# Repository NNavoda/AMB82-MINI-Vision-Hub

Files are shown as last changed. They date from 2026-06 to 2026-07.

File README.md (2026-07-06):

# AMB82-MINI Vision Hub & Distributed Robotic Car Platform

> **Platform:** Realtek AMB82-MINI, ESP32, ESP32-C3  
> **Status:** `v1.4 — ESP-NOW Mecanum Car + AI Vision Hub + Head Tracker`

---

## 📌 Project Overview

This repository contains the firmware for a **distributed, multi-node autonomous robotic car system**. The system is decoupled into multiple independent nodes communicating over Wi-Fi and ESP-NOW:
1. **Vision Hub (AMB82-MINI)**: A dedicated AI camera unit streaming live video over RTSP and running real-time object detection (YOLOv4-Tiny) using its on-chip NPU.
2. **Motor Control Node (ESP32)**: Receives low-latency ESP-NOW commands to independently drive 4 DC motors (via two TB6612FNG drivers) in an omnidirectional Mecanum drive configuration, and controls the camera Pan/Tilt servos.
3. **Gesture Glove Controller (ESP32-C3)**: A wearable glove equipped with an MPU-6050 IMU that calculates Mecanum kinematics from hand tilt/twist and transmits them directly to the car via ESP-NOW.
4. **Head Tracker Unit (ESP32-C3)**: A head-mounted IMU (MPU-9250) that calculates head Pitch and Yaw to seamlessly aim the Pan/Tilt Vision Hub camera in real time via ESP-NOW.

### System Architecture

```text
┌────────────────────────────────────────────────────────────────────────┐
│                   Distributed Robotic Car Platform                     │
│                                                                        │
│  ┌───────────────┐           ┌──────────────────────────────┐          │
│  │ Gesture Glove │  ESP-NOW  │        ESP32 Car Node        │          │
│  │ (ESP32-C3 +   ├──────────►│  (ESP32 + 2x TB6612FNG +     │          │
│  │  MPU-6050)    │ Protocol  │   Mecanum Wheels + Servos)   │          │
│  └───────────────┘           └────────────┬─────────────────┘          │
│                                           │                            │
│  ┌───────────────┐  ESP-NOW               │                            │
│  │ Head Tracker  ├──────────►             │                            │
│  │ (ESP32-C3 +   │                        │                            │
│  │  MPU-9250)    │           ┌────────────▼─────────────────┐          │
│  └───────────────┘           │  Viewer / Driver Dashboard   │          │
│                              │  (VLC Player / Phone VR)     │          │
│  ┌───────────────┐   WiFi    │                              │          │
│  │  AMB82-MINI   ├──────────►│                              │          │
│  │  Vision Hub   │ RTSP / AP │                              │          │
│  └───────────────┘           └──────────────────────────────┘          │
└────────────────────────────────────────────────────────────────────────┘
```

---

## ✨ Features

### 📡 **Vision Hub (AMB82-MINI)**
- **RTSP Stream**: H.264 · VGA (640×480) · 20fps · 1 Mbps · Low-latency GOP=10
- **Object Detection**: YOLOv4-Tiny · INT8 NPU · COCO 80 classes
- **Live OSD Overlay**: Bounding boxes + class labels composited before H.264 encoding

### 🚗 **Car Control Node (ESP32)**
- **ESP-NOW Receiver**: Ultra-low latency, direct peer-to-peer connection.
- **Mecanum Omnidirectional Drive**: Controls 4 independent motors via dual TB6612FNG H-bridges allowing for strafing, diagonal movement, and zero-radius turns.
- **Pan/Tilt Camera Gimbal**: Instantly receives angles from the head tracker and drives two servos with 16-bit PWM to smoothly aim the AMB82-MINI camera.
- **Safety Timeout**: Automatically halts all motors and centers servos if the ESP-NOW connection drops for >500ms.

### 🧤 **Gesture Glove (ESP32-C3)**
- **MPU-6050 IMU**: Fuses accelerometer and gyroscope data using a complementary filter for stable pitch/roll/yaw calculation.
- **Mecanum Kinematics**:
  - **Pitch** (Tilt Forward/Back) = Forward / Reverse Drive
  - **Roll** (Tilt Left/Right) = Strafe Left / Right
  - **Yaw** (Twist Hand) = Tank Spin in place

### 🥽 **Head Tracker Unit (ESP32-C3)**
- **MPU-9250 IMU**: Calculates true pitch/roll and integrates gyroscope Z-axis for responsive yaw mapping.
- **Zero-Drift Centering**: Remotely zeros the pan (yaw) heading simply by pressing the BOOT button on the Car Receiver.
- **Proportional Scaling**: Head movements are smoothly multiplied by a tuned sensitivity curve (Pitch x1.8, Yaw x1.5) to capture full camera range (40°–180°) effortlessly.

---

## 📁 Project Structure

```text
AMB82-MINI-Vision-Hub/
├── RTSP/
│   ├── RTSP.ino                  # AMB82-MINI Vision Hub firmware
│   └── ObjectClassList.h         # COCO 80-class lookup table
├── ESP32-Car/
│   ├── ESPNOW_Receiver/          
│   │   └── ESPNOW_Receiver.ino   # ESP32 ESP-NOW Mecanum Motor Controller
│   ├── HeadTracker_Receiver/     
│   │   └── HeadTracker_Receiver.ino # ESP32 ESP-NOW Servo Receiver (Latest)
│   ├── ESPNOW_ServoTracker/
│   │   └── ESPNOW_ServoTracker.ino # (Legacy) ESP-NOW Pan/Tilt Head Tracker
│   └── WebMotorControl/          # (Legacy) HTTP Web Dashboard Controller
├── Gesture_Glove/
│   └── Gesture_Glove.ino         # ESP32-C3 ESP-NOW IMU Glove Controller
├── HeadTracker/
│   └── HeadTracker.ino           # ESP32-C3 + MPU9250 Head Tracker Sender
├── 3D Files/                     # 3D printable parts for the robot chassis
├── .vscode/
│   └── ...                       # Editor configurations
└── README.md
```

---

## 🛠️ Hardware Requirements

- **Vision**: Realtek AMB82-MINI development board + camera module
- **Car**: ESP32 Dev Module (30-pin), 2x TB6612FNG motor drivers, 4x Mecanum wheels w/ DC Motors, Chassis.
- **Glove**: ESP32-C3 Super Mini, MPU-6050 GY-521 IMU module, 3.7V Battery.

---

## 🚀 Setup & Usage

### 1. Car Setup (ESP32)
1. Flash `ESP32-Car/ESPNOW_Receiver/ESPNOW_Receiver.ino` to the ESP32.
2. The ESP32 will boot and wait for incoming ESP-NOW packets on its MAC address.

### 2. Vision Hub (AMB82-MINI)
1. Flash `RTSP/RTSP.ino` to the AMB82-MINI.
2. Connect to its `RobotCar-Demo` Wi-Fi AP.
3. Open `rtsp://192.168.1.1:554/` in VLC Media Player to view the live object detection stream.

### 3. Gesture Glove (ESP32-C3)
1. Ensure the Car's MAC address is correctly hardcoded in `Gesture_Glove.ino`.
2. Flash `Gesture_Glove/Gesture_Glove.ino` to the ESP32-C3.
3. Put the glove on. Tilting and twisting your hand will instantly drive the Mecanum wheels.

---

## 🗺️ Roadmap

- [x] **v1.0** — Vision Hub: RTSP streaming + YOLOv4 object detection OSD
- [x] **v1.1** — Decentralized nodes: Car web controller + IMU Gesture Glove
- [x] **v1.2** — ESP-NOW upgrade: Ultra-low latency Mecanum drive kinematics
- [x] **v1.3** — Servo Protocol: Preliminary Pan/Tilt absolute tracking
- [x] **v1.4** — Head Tracker Unit: Full 2-axis independent tracking with IMU MPU-9250
- [ ] **v2.0** — Full autonomous navigation loop (Vision Hub sending UDP drive commands)

---

## 📄 License

MIT © 2026 [NNavoda](https://github.com/NNavoda)

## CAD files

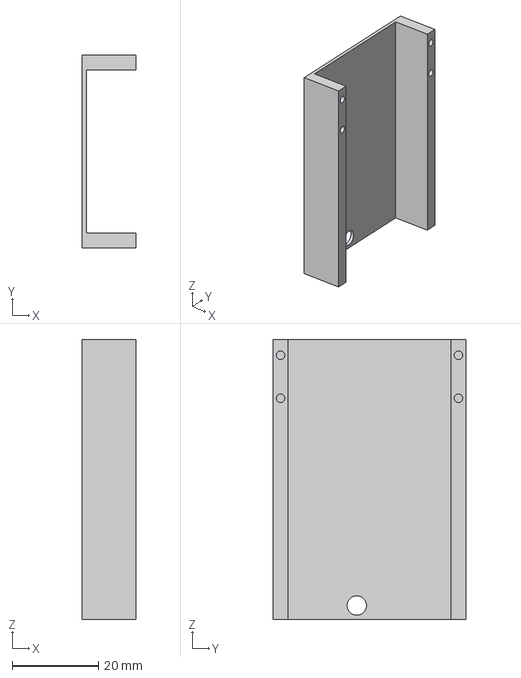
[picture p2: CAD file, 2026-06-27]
3D Files/Pan Tilt Servo/Bracket 2.3mf
12.5 x 44.9 x 65.0 mm

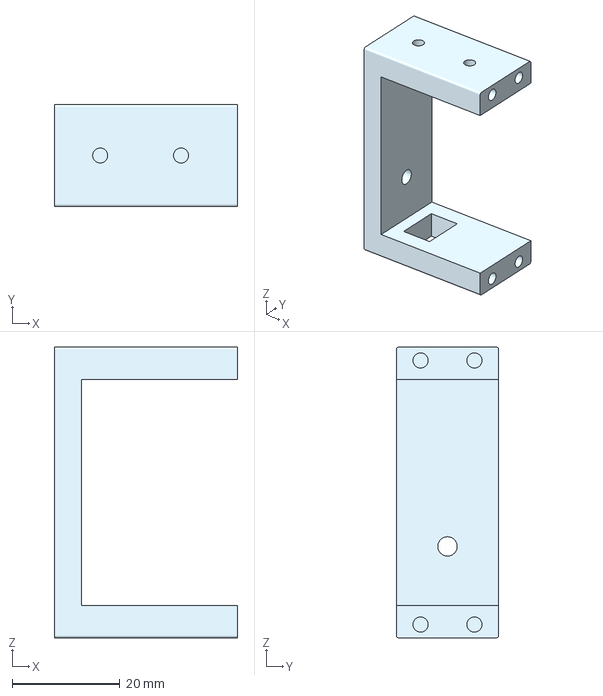
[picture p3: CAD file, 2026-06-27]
3D Files/Pan Tilt Servo/Top Bracket.3mf
34.0 x 19.0 x 54.0 mm

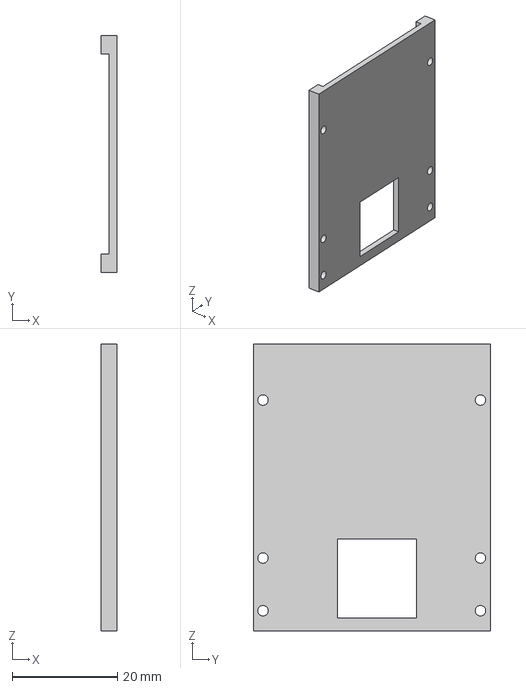
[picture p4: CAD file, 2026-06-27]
3D Files/Pan Tilt Servo/Bracket1 v2.3mf
3.00 x 45.0 x 54.5 mm

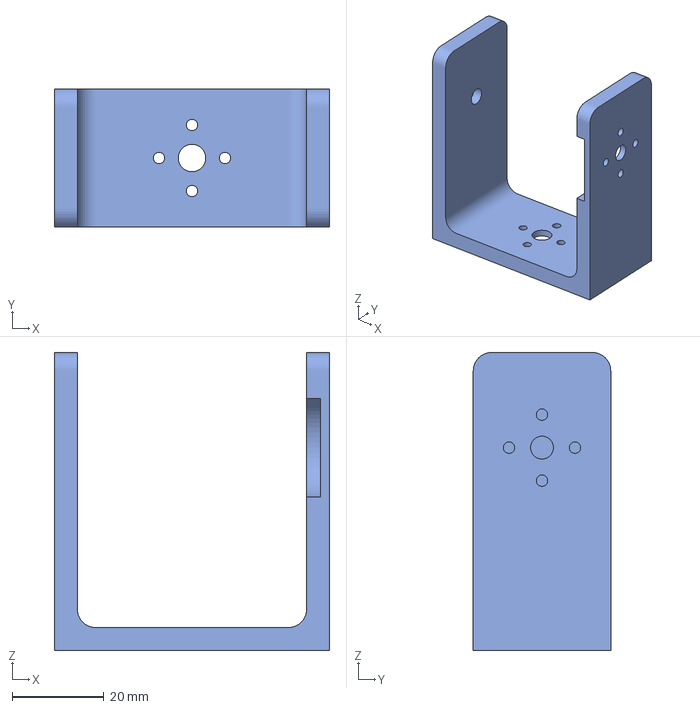
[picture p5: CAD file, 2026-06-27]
3D Files/Pan Tilt Servo/Bottom Bracket.3mf
60.0 x 30.0 x 65.0 mm

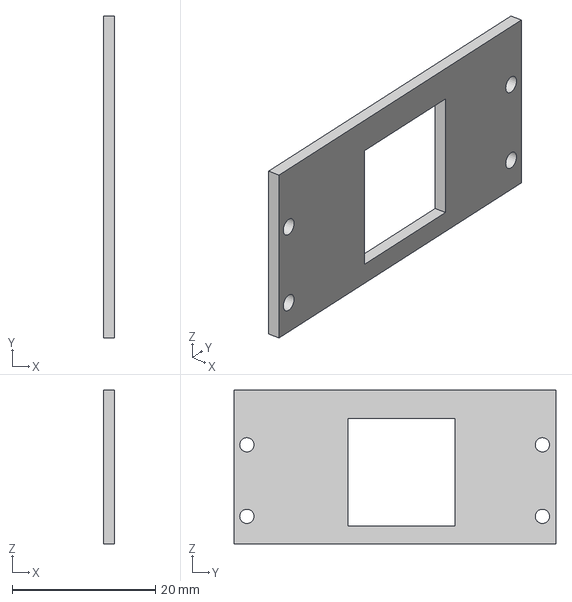
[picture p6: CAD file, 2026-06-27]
3D Files/Pan Tilt Servo/Bracket1.3mf
1.50 x 45.0 x 21.5 mm

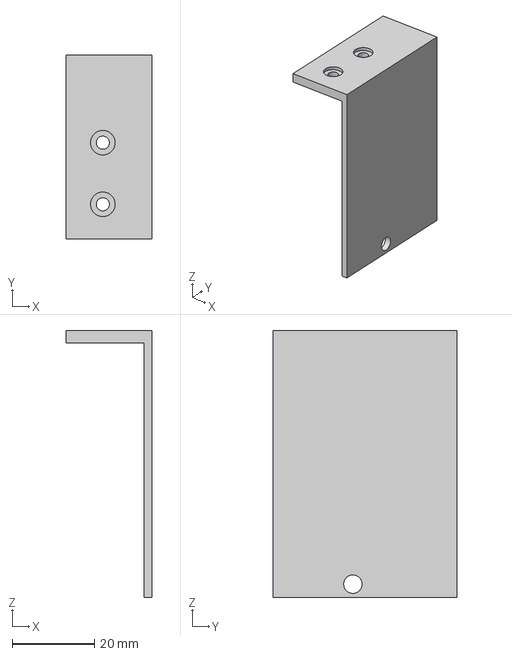
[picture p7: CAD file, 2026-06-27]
3D Files/Pan Tilt Servo/Bracket 3.3mf
21.0 x 44.9 x 65.0 mm

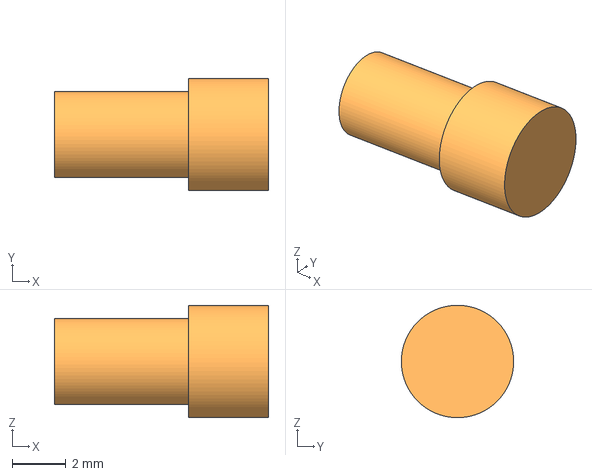
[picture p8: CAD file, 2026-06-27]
3D Files/Pan Tilt Servo/Mount.3mf
8.00 x 4.20 x 4.20 mm

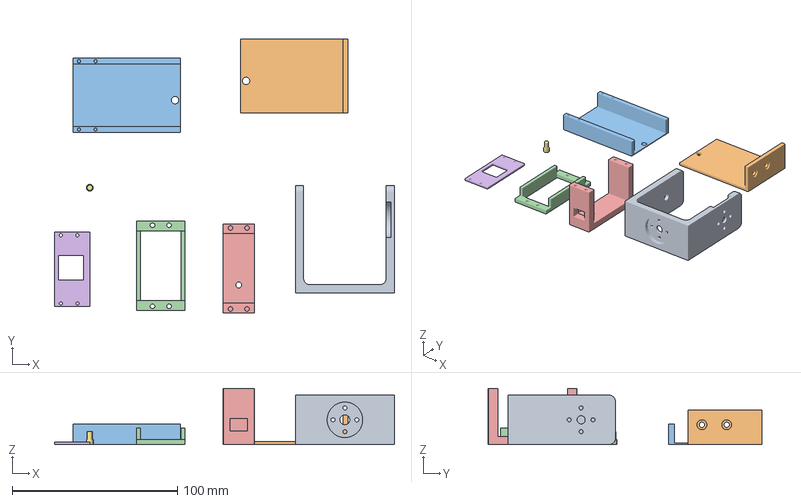
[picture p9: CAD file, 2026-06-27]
3D Files/Pan Tilt Servo/Base.3mf
205.7 x 165.9 x 34.0 mm

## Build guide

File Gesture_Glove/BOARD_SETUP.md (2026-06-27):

# ESP32-C3 Super Mini — Board Setup & Driver Fix Guide

## Problem: Board not appearing in Device Manager

The ESP32-C3 Super Mini uses a **USB-CDC on-chip** interface (no external USB-UART chip like CH340 or CP2102).
Windows requires a specific driver + a boot trick to enumerate it.

---

## Step 1 — Force the board into Download/Bootloader Mode

The board will **not** appear in Device Manager unless it is in Download Mode.

| Step | Action |
|---|---|
| 1 | Hold down the **BOOT** button (label: `BOOT` or `IO9`) |
| 2 | While holding BOOT, press and release the **RESET** button (label: `RST` or `EN`) |
| 3 | Release the **BOOT** button |
| 4 | Open **Device Manager** — it should now appear as `USB Serial Device (COMx)` or `Unknown Device` |

> If it appears as **Unknown Device**, proceed to Step 2.

---

## Step 2 — Install the ESP32-C3 USB-CDC Driver (Windows)

### Option A — Automatic via Zadig (Recommended for first-time)

1. Download **Zadig** from https://zadig.akeo.ie/
2. Open Zadig → Options → `List All Devices`
3. Find **`USB JTAG/serial debug unit`** or **`ESP32-C3`** in the dropdown
4. Set the driver to **`usbser (USB Serial)`** or **`WinUSB`**
5. Click **Install Driver** / **Replace Driver**

### Option B — Windows Update Driver Manually

1. Device Manager → right-click the Unknown Device → **Update driver**
2. Choose **Browse my computer** → **Let me pick from a list**
3. Select **Ports (COM & LPT)** → **USB Serial Device**

### Option C — Install ESP-IDF USB Driver package

Download and run the official driver installer:
```
https://dl.espressif.com/dl/idf-driver/idf-driver-esp32-usb-jtag-2021-07-15.zip
```
Extract and run `install.bat` as Administrator.

---

## Step 3 — Install the ESP32 Board Package in Arduino IDE

1. Open Arduino IDE → **File → Preferences**
2. In **"Additional boards manager URLs"** add:
   ```
   https://raw.githubusercontent.com/espressif/arduino-esp32/gh-pages/package_esp32_index.json
   ```
3. Go to **Tools → Board → Boards Manager**
4. Search `esp32` → install **"esp32 by Espressif Systems"** (v2.0.17+ or v3.x)

---

## Step 4 — Arduino IDE Board & Port Settings

| Setting | Value |
|---|---|
| **Board** | `ESP32C3 Dev Module` |
| **USB CDC On Boot** | `Enabled` ← **CRITICAL** |
| **Upload Speed** | `921600` |
| **CPU Frequency** | `160MHz` |
| **Flash Mode** | `DIO` |
| **Flash Size** | `4MB (32Mb)` |
| **Partition Scheme** | `Default 4MB with spiffs` |
| **Core Debug Level** | `None` |
| **Erase All Flash** | `Disabled` |
| **Port** | Select the COM port that appeared |

> **USB CDC On Boot → Enabled** is mandatory. Without it, `Serial.begin()` outputs to the UART0 pins,
> not the USB port, and you will see nothing in the Serial Monitor.

---

## Step 5 — Uploading the Sketch

1. Hold **BOOT**, press **RESET**, release **BOOT** (enter Download Mode)
2. Click **Upload** in Arduino IDE
3. When you see `Connecting........_____` stop holding BOOT
4. After upload finishes, press **RESET** once to run the firmware
5. Open Serial Monitor at **115200 baud**

---

## Expected Serial Output

```
==============================================
  Gesture Glove — ESP32-C3 Super Mini BOOT
==============================================
  LED_PIN  : GPIO 8  configured as OUTPUT
  Connecting to SSID : "Redmi Note 10 Pro"
  Entering main loop (non-blocking)…
----------------------------------------------

  ✓  Wi-Fi CONNECTED!
     SSID       : Redmi Note 10 Pro
     IP Address : 192.168.x.x
     Gateway    : 192.168.x.1
     RSSI       : -45 dBm
     Channel    : 6
----------------------------------------------
  LED → FAST BLINK (4 Hz) — handshake OK
```

---

## LED Behaviour Summary

| State | Pattern | Frequency |
|---|---|---|
| Connecting to Wi-Fi | Slow blink | 1 Hz (500ms ON / 500ms OFF) |
| Connected | Fast blink | 4 Hz (125ms ON / 125ms OFF) |
| Disconnected (after connection) | Slow blink + auto-reconnect | 1 Hz |

---

## Troubleshooting

| Symptom | Fix |
|---|-----|
| Nothing in Device Manager | Hold BOOT → press RESET → release BOOT |
| `A fatal error occurred: Failed to connect` | Not in download mode — repeat BOOT+RESET sequence |
| Serial monitor blank | Set **USB CDC On Boot → Enabled** and re-upload |
| LED not blinking | Wrong LED_PIN — try `#define LED_PIN 8` or `2` depending on board revision |
| Keeps disconnecting | Move closer to AP, or check SSID/password in sketch |

---

## Next Phase: MPU-6050 Gesture Pipeline

```
SDA → GPIO 6
SCL → GPIO 7
VCC → 3.3V
GND → GND
```

Wire up the MPU-6050 and the I²C address defaults to `0x68`.
The next sketch will add the gesture classification layer.

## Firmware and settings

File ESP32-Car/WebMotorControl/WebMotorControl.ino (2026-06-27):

// ============================================================
//  WebMotorControl.ino
//  Web-dashboard motor + camera servo controller
//  Board  : ESP32 Dev Module (30-pin)
//  Motors : TB6612FNG dual H-bridge (×2)
//  Servos : MG996R pan (D21) + tilt (D22), 180° range
//  WiFi   : connects to phone hotspot, hosts HTTP server
// ============================================================

#include <WiFi.h>
#include <WebServer.h>

// ----------------------------------------------------------
// WiFi credentials
// ----------------------------------------------------------
const char* SSID     = "Redmi Note 10 Pro";
const char* PASSWORD = "00000007";

// ----------------------------------------------------------
// PIN DEFINITIONS — LEFT MOTOR CONTROLLER
// ----------------------------------------------------------
#define M_FL_PWMA  13
#define M_FL_AIN1   4
#define M_FL_AIN2  16   // Hardware RX2

#define M_RL_BIN1  17   // Hardware TX2
#define M_RL_BIN2  18
#define M_RL_PWMB  19

// ----------------------------------------------------------
// PIN DEFINITIONS — RIGHT MOTOR CONTROLLER
//   FR motor : B-channel (BIN1, BIN2, PWMB)
//   RR motor : A-channel (AIN1, AIN2, PWMA)
// ----------------------------------------------------------
#define M_FR_BIN1  26
#define M_FR_BIN2  27
#define M_FR_PWMB  14

#define M_RR_AIN1  33
#define M_RR_AIN2  25
#define M_RR_PWMA  32

// ----------------------------------------------------------
// PIN DEFINITIONS — CAMERA SERVO (MG996R, 180°)
// ----------------------------------------------------------
#define SERVO_PAN   21   // Horizontal servo — GPIO 21
#define SERVO_TILT  22   // Vertical servo   — GPIO 22

// ----------------------------------------------------------
// Motor PWM parameters (5 kHz, 8-bit)
// ----------------------------------------------------------
const int PWM_FREQ = 5000;
const int PWM_RES  = 8;       // 0–255

// ----------------------------------------------------------
// Servo PWM parameters (50 Hz, 16-bit for fine resolution)
//   MG996R pulse: 500 µs (0°) → 1500 µs (90°) → 2500 µs (180°)
//   At 50 Hz, period = 20 ms = 20000 µs
//   Duty at 16-bit (65536 steps):
//     0°  → 500/20000 × 65536 = 1638
//     90° → 1500/20000 × 65536 = 4915
//    180° → 2500/20000 × 65536 = 8192
// ----------------------------------------------------------
const int SERVO_FREQ = 50;
const int SERVO_RES  = 16;
const int SERVO_MIN  = 1638;   // 500 µs pulse  → 0°
const int SERVO_MAX  = 8192;   // 2500 µs pulse → 180°

// ----------------------------------------------------------
// Servo calibration & limits
//   Hard lower limit = 50° (below this the bracket collides)
//   Pan  : physical 113° = camera straight-ahead
//          INVERTED — higher slider value → camera moves RIGHT
//          Slider centre = 230 - 113 = 117  (230 = 50+180)
//   Tilt : physical 135° = camera straight-ahead (standard, not inverted)
// ----------------------------------------------------------
const int SERVO_LIMIT_MIN = 50;    // degrees — hard lower bound
const int SERVO_LIMIT_MAX = 180;   // degrees — hard upper bound
const int PAN_PHYS_CENTER  = 113;  // physical servo angle for straight-ahead
const int TILT_PHYS_CENTER = 135;  // physical servo angle for straight-ahead
// Slider value that maps to PAN_PHYS_CENTER after inversion:
//   slider_center = LIMIT_MIN + LIMIT_MAX - PAN_PHYS_CENTER = 50+180-113 = 117
const int PAN_SLIDER_CENTER  = 117;
const int TILT_SLIDER_CENTER = 135;

// ----------------------------------------------------------
// Web server on port 80
// ----------------------------------------------------------
WebServer server(80);

// Current state
int speedFL = 0, speedFR = 0, speedRL = 0, speedRR = 0;
int anglePan  = PAN_SLIDER_CENTER;   // slider value
int angleTilt = TILT_SLIDER_CENTER;  // slider value (= physical for tilt)

// ----------------------------------------------------------
// Servo helpers
// ----------------------------------------------------------

void writeServo(int pin, int angle) {
  int duty = map(angle, 0, 180, SERVO_MIN, SERVO_MAX);
  ledcWrite(pin, duty);
}

// ----------------------------------------------------------
// Motor drive helpers
// ----------------------------------------------------------

/** Drive Front-Left (inverted direction logic from MotorTest) */
void driveFL(int spd) {
  if (spd == 0) {
    digitalWrite(M_FL_AIN1, LOW); digitalWrite(M_FL_AIN2, LOW);
    ledcWrite(M_FL_PWMA, 0);
  } else if (spd > 0) {
    digitalWrite(M_FL_AIN1, LOW);  digitalWrite(M_FL_AIN2, HIGH);
    ledcWrite(M_FL_PWMA, spd);
  } else {
    digitalWrite(M_FL_AIN1, HIGH); digitalWrite(M_FL_AIN2, LOW);
    ledcWrite(M_FL_PWMA, -spd);
  }
}

/** Drive Front-Right — B-channel (BIN1=GPIO26, BIN2=GPIO14, PWMB=GPIO27) */
void driveFR(int spd) {
  if (spd == 0) {
    digitalWrite(M_FR_BIN1, LOW); digitalWrite(M_FR_BIN2, LOW);
    ledcWrite(M_FR_PWMB, 0);
  } else if (spd > 0) {
    digitalWrite(M_FR_BIN1, HIGH); digitalWrite(M_FR_BIN2, LOW);
    ledcWrite(M_FR_PWMB, spd);
  } else {
    digitalWrite(M_FR_BIN1, LOW);  digitalWrite(M_FR_BIN2, HIGH);
    ledcWrite(M_FR_PWMB, -spd);
  }
}

/** Drive Rear-Left (standard direction logic from MotorTest) */
void driveRL(int spd) {
  if (spd == 0) {
    digitalWrite(M_RL_BIN1, LOW); digitalWrite(M_RL_BIN2, LOW);
    ledcWrite(M_RL_PWMB, 0);
  } else if (spd > 0) {
    digitalWrite(M_RL_BIN1, HIGH); digitalWrite(M_RL_BIN2, LOW);
    ledcWrite(M_RL_PWMB, spd);
  } else {
    digitalWrite(M_RL_BIN1, LOW);  digitalWrite(M_RL_BIN2, HIGH);
    ledcWrite(M_RL_PWMB, -spd);
  }
}

/** Drive Rear-Right — A-channel (AIN1=GPIO33, AIN2=GPIO25, PWMA=GPIO32) */
void driveRR(int spd) {
  if (spd == 0) {
    digitalWrite(M_RR_AIN1, LOW); digitalWrite(M_RR_AIN2, LOW);
    ledcWrite(M_RR_PWMA, 0);
  } else if (spd > 0) {
    digitalWrite(M_RR_AIN1, LOW);  digitalWrite(M_RR_AIN2, HIGH);
    ledcWrite(M_RR_PWMA, spd);
  } else {
    digitalWrite(M_RR_AIN1, HIGH); digitalWrite(M_RR_AIN2, LOW);
    ledcWrite(M_RR_PWMA, -spd);
  }
}

void allStop() {
  driveFL(0); driveFR(0); driveRL(0); driveRR(0);
  speedFL = speedFR = speedRL = speedRR = 0;
}

// ----------------------------------------------------------
// HTML dashboard (PROGMEM)
// ----------------------------------------------------------
const char INDEX_HTML[] PROGMEM = R"rawhtml(
<!DOCTYPE html>
<html lang="en">
<head>
  <meta charset="UTF-8"/>
  <meta name="viewport" content="width=device-width, initial-scale=1.0"/>
  <title>ESP32 Car — Motor &amp; Camera Dashboard</title>
  <style>
    @import url('https://fonts.googleapis.com/css2?family=Outfit:wght@300;400;600;700;900&display=swap');

    *, *::before, *::after { box-sizing: border-box; margin: 0; padding: 0; }

    :root {
      --bg:        #0d0f14;
      --card:      #161b26;
      --border:    #1f2a3a;
      --accent:    #00d4ff;
      --fwd:       #00e5a0;
      --rev:       #ff4f6e;
      --stop:      #4a5568;
      --servo:     #a78bfa;
      --servo-low: #f59e0b;
      --text:      #e2e8f0;
      --sub:       #7a8ba0;
      --radius:    16px;
      --shadow:    0 8px 32px rgba(0,0,0,0.5);
    }

    body {
      font-family: 'Outfit', sans-serif;
      background: var(--bg);
      color: var(--text);
      min-height: 100vh;
      display: flex;
      flex-direction: column;
      align-items: center;
      padding: 24px 16px 48px;
    }

    /* ---- HEADER ---- */
    header { text-align: center; margin-bottom: 28px; }
    header h1 {
      font-size: 2rem; font-weight: 900; letter-spacing: -0.5px;
      background: linear-gradient(135deg, var(--accent), #7b5cff);
      -webkit-background-clip: text; -webkit-text-fill-color: transparent;
    }
    header p { color: var(--sub); font-size: 0.85rem; margin-top: 4px; }
    #ip-badge {
      display: inline-block; margin-top: 10px;
      background: var(--card); border: 1px solid var(--border);
      border-radius: 50px; padding: 4px 14px;
      font-size: 0.78rem; color: var(--accent); letter-spacing: 0.5px;
    }

    /* ---- SECTION TITLES ---- */
    .section-title {
      width: 100%; max-width: 560px;
      display: flex; align-items: center; gap: 10px;
      margin: 24px 0 12px;
      font-size: 0.75rem; font-weight: 700; letter-spacing: 1.5px;
      text-transform: uppercase; color: var(--sub);
    }
    .section-title::after {
      content: ''; flex: 1; height: 1px; background: var(--border);
    }

    /* ---- MOTOR GRID (2×2) ---- */
    .car-grid {
      display: grid; grid-template-columns: 1fr 1fr;
      gap: 14px; width: 100%; max-width: 560px;
    }

    /* ---- MOTOR CARD ---- */
    .motor-card {
      background: var(--card); border: 1px solid var(--border);
      border-radius: var(--radius); padding: 18px 16px 14px;
      box-shadow: var(--shadow); display: flex; flex-direction: column;
      gap: 10px; transition: border-color 0.25s;
    }
    .motor-card:hover { border-color: var(--accent); }

    .motor-header { display: flex; justify-content: space-between; align-items: center; }
    .motor-label  { font-weight: 700; font-size: 0.95rem; letter-spacing: 0.4px; }
    .motor-badge  {
      font-size: 0.7rem; font-weight: 600; padding: 3px 10px;
      border-radius: 50px; background: #1a2235; border: 1px solid var(--border);
      color: var(--sub); text-transform: uppercase; transition: all 0.2s;
    }
    .motor-badge.fwd { background:#0a2e22; border-color:var(--fwd); color:var(--fwd); }
    .motor-badge.rev { background:#2e0a14; border-color:var(--rev); color:var(--rev); }

    .speed-row {
      display: flex; align-items: center; justify-content: space-between;
      font-size: 0.8rem; color: var(--sub);
    }
    .speed-val {
      font-size: 1.5rem; font-weight: 700; color: var(--text);
      min-width: 55px; text-align: right; transition: color 0.2s;
    }
    .speed-val.fwd { color: var(--fwd); }
    .speed-val.rev { color: var(--rev); }

    /* ---- SERVO GRID (1×2) ---- */
    .servo-grid {
      display: grid; grid-template-columns: 1fr 1fr;
      gap: 14px; width: 100%; max-width: 560px;
    }

    /* ---- SERVO CARD ---- */
    .servo-card {
      background: var(--card); border: 1px solid var(--border);
      border-radius: var(--radius); padding: 18px 16px 14px;
      box-shadow: var(--shadow); display: flex; flex-direction: column;
      gap: 10px; transition: border-color 0.25s;
    }
    .servo-card:hover { border-color: var(--servo); }

    .servo-header { display: flex; justify-content: space-between; align-items: center; }
    .servo-label  { font-weight: 700; font-size: 0.95rem; letter-spacing: 0.4px; }
    .servo-badge  {
      font-size: 0.75rem; font-weight: 700; padding: 3px 10px;
      border-radius: 50px; background: #1a1535; border: 1px solid var(--servo);
      color: var(--servo);
    }

    .angle-row {
      display: flex; align-items: center; justify-content: space-between;
      font-size: 0.8rem; color: var(--sub);
    }
    .angle-val {
      font-size: 1.5rem; font-weight: 700; color: var(--servo);
      min-width: 55px; text-align: center;
    }

    /* ---- SHARED SLIDER STYLE ---- */
    input[type=range] {
      -webkit-appearance: none; width: 100%; height: 6px;
      border-radius: 3px; outline: none; cursor: pointer;
    }
    /* Motor slider: rev→stop→fwd gradient */
    .motor-card input[type=range] {
      background: linear-gradient(to right, var(--rev) 0%, var(--stop) 50%, var(--fwd) 100%);
    }
    /* Servo slider: amber→purple gradient */
    .servo-card input[type=range] {
      background: linear-gradient(to right, var(--servo-low) 0%, var(--servo) 100%);
    }
    input[type=range]::-webkit-slider-thumb {
      -webkit-appearance: none; width: 22px; height: 22px;
      border-radius: 50%; background: var(--accent);
      border: 3px solid var(--bg);
      box-shadow: 0 0 8px rgba(0,212,255,0.6);
      cursor: pointer; transition: box-shadow 0.2s, transform 0.15s;
    }
    .servo-card input[type=range]::-webkit-slider-thumb {
      background: var(--servo);
      box-shadow: 0 0 8px rgba(167,139,250,0.6);
    }
    input[type=range]:active::-webkit-slider-thumb {
      transform: scale(1.2); box-shadow: 0 0 16px rgba(0,212,255,0.9);
    }
    .servo-card input[type=range]:active::-webkit-slider-thumb {
      box-shadow: 0 0 16px rgba(167,139,250,0.9);
    }

    /* ---- STOP / CENTER BUTTONS (per card) ---- */
    .btn-stop-motor, .btn-center-servo {
      width: 100%; padding: 8px; border-radius: 10px;
      border: 1px solid var(--border); background: #1a2235;
      font-family: 'Outfit', sans-serif; font-size: 0.8rem; font-weight: 600;
      letter-spacing: 0.5px; cursor: pointer; transition: all 0.2s; color: var(--sub);
    }
    .btn-stop-motor:hover  { background:#ff4f6e22; border-color:var(--rev); color:var(--rev); }
    .btn-center-servo:hover{ background:#a78bfa22; border-color:var(--servo); color:var(--servo); }

    /* ---- GLOBAL CONTROLS ---- */
    .global-controls {
      margin-top: 16px; width: 100%; max-width: 560px;
      display: flex; gap: 12px;
    }
    .btn {
      flex: 1; padding: 13px; border-radius: var(--radius); border: none;
      font-family: 'Outfit', sans-serif; font-size: 0.92rem; font-weight: 700;
      letter-spacing: 0.5px; cursor: pointer; transition: opacity 0.2s, transform 0.15s;
    }
    .btn:active { transform: scale(0.97); }
    .btn-all-stop {
      background: linear-gradient(135deg, #ff4f6e, #c0002a); color: #fff;
      box-shadow: 0 4px 20px rgba(255,79,110,0.4);
    }
    .btn-all-fwd {
      background: linear-gradient(135deg, #00e5a0, #00897b); color: #000;
      box-shadow: 0 4px 20px rgba(0,229,160,0.3);
    }
    .btn-center-all-cam {
      background: linear-gradient(135deg, #a78bfa, #6d28d9); color: #fff;
      box-shadow: 0 4px 20px rgba(167,139,250,0.35);
    }

    /* ---- STATUS BAR ---- */
    #status-bar {
      margin-top: 20px; width: 100%; max-width: 560px;
      background: var(--card); border: 1px solid var(--border);
      border-radius: var(--radius); padding: 11px 16px;
      font-size: 0.77rem; color: var(--sub);
      display: flex; justify-content: space-between; align-items: center;
    }
    #status-dot {
      width: 8px; height: 8px; border-radius: 50%; background: #888;
      display: inline-block; margin-right: 6px; transition: background 0.3s;
    }
    #status-dot.ok  { background: var(--fwd); box-shadow: 0 0 6px var(--fwd); }
    #status-dot.err { background: var(--rev); box-shadow: 0 0 6px var(--rev); }
  </style>
</head>
<body>

<header>
  <h1>🚗 ESP32 Car Dashboard</h1>
  <p>Motor drive &amp; Camera pan/tilt control</p>
  <div id="ip-badge">Loading IP…</div>
</header>

<!-- ====== MOTOR SECTION ====== -->
<div class="section-title">🔧 Drive Motors</div>

<div class="car-grid">

  <!-- FL -->
  <div class="motor-card">
    <div class="motor-header">
      <span class="motor-label">↖ Front Left</span>
      <span class="motor-badge" id="badge-fl">STOP</span>
    </div>
    <div class="speed-row">
      <span>REV ←</span>
      <span class="speed-val" id="val-fl">0</span>
      <span>→ FWD</span>
    </div>
    <input type="range" id="sl-fl" min="-255" max="255" value="0"
           oninput="onSlider('fl', this.value)" onchange="sendSpeed('fl', this.value)"/>
    <button class="btn-stop-motor" onclick="stopMotor('fl')">⏹ Stop FL</button>
  </div>

  <!-- FR -->
  <div class="motor-card">
    <div class="motor-header">
      <span class="motor-label">Front Right ↗</span>
      <span class="motor-badge" id="badge-fr">STOP</span>
    </div>
    <div class="speed-row">
      <span>REV ←</span>
      <span class="speed-val" id="val-fr">0</span>
      <span>→ FWD</span>
    </div>
    <input type="range" id="sl-fr" min="-255" max="255" value="0"
           oninput="onSlider('fr', this.value)" onchange="sendSpeed('fr', this.value)"/>
    <button class="btn-stop-motor" onclick="stopMotor('fr')">⏹ Stop FR</button>
  </div>

  <!-- RL -->
  <div class="motor-card">
    <div class="motor-header">
      <span class="motor-label">↙ Rear Left</span>
      <span class="motor-badge" id="badge-rl">STOP</span>
    </div>
    <div class="speed-row">
      <span>REV ←</span>
      <span class="speed-val" id="val-rl">0</span>
      <span>→ FWD</span>
    </div>
    <input type="range" id="sl-rl" min="-255" max="255" value="0"
           oninput="onSlider('rl', this.value)" onchange="sendSpeed('rl', this.value)"/>
    <button class="btn-stop-motor" onclick="stopMotor('rl')">⏹ Stop RL</button>
  </div>

  <!-- RR -->
  <div class="motor-card">
    <div class="motor-header">
      <span class="motor-label">Rear Right ↘</span>
      <span class="motor-badge" id="badge-rr">STOP</span>
    </div>
    <div class="speed-row">
      <span>REV ←</span>
      <span class="speed-val" id="val-rr">0</span>
      <span>→ FWD</span>
    </div>
    <input type="range" id="sl-rr" min="-255" max="255" value="0"
           oninput="onSlider('rr', this.value)" onchange="sendSpeed('rr', this.value)"/>
    <button class="btn-stop-motor" onclick="stopMotor('rr')">⏹ Stop RR</button>
  </div>

</div>

<!-- Motor global controls -->
<div class="global-controls">
  <button class="btn btn-all-stop" onclick="stopAll()">⏹ STOP ALL</button>
  <button class="btn btn-all-fwd"  onclick="allForward()">▶ ALL FORWARD</button>
</div>

<!-- ====== CAMERA SECTION ====== -->
<div class="section-title">📷 Camera Pan / Tilt</div>

<div class="servo-grid">

  <!-- PAN (horizontal, D21) — inverted: slider↑ = camera RIGHT -->
  <div class="servo-card">
    <div class="servo-header">
      <span class="servo-label">↔ Pan</span>
      <span class="servo-badge" id="badge-pan">117°</span>
    </div>
    <div class="angle-row">
      <span>← LEFT</span>
      <span class="angle-val" id="val-pan">117</span>
      <span>RIGHT →</span>
    </div>
    <input type="range" id="sl-pan" min="50" max="180" value="117"
           oninput="onServo('pan', this.value)" onchange="sendServo('pan', this.value)"/>
    <button class="btn-center-servo" onclick="centerServo('pan')">⊙ Centre Pan</button>
  </div>

  <!-- TILT (vertical, D22) — direct: slider↑ = camera UP -->
  <div class="servo-card">
    <div class="servo-header">
      <span class="servo-label">↕ Tilt</span>
      <span class="servo-badge" id="badge-tilt">135°</span>
    </div>
    <div class="angle-row">
      <span>↓ DOWN</span>
      <span class="angle-val" id="val-tilt">135</span>
      <span>UP ↑</span>
    </div>
    <input type="range" id="sl-tilt" min="50" max="180" value="135"
           oninput="onServo('tilt', this.value)" onchange="sendServo('tilt', this.value)"/>
    <button class="btn-center-servo" onclick="centerServo('tilt')">⊙ Centre Tilt</button>
  </div>

</div>

<!-- Servo global control -->
<div class="global-controls">
  <button class="btn btn-center-all-cam" onclick="centerAll()">⊙ CENTRE CAMERA</button>
</div>

<!-- ====== STATUS BAR ====== -->
<div id="status-bar">
  <span><span id="status-dot"></span><span id="status-msg">Initialising…</span></span>
  <span id="last-cmd">—</span>
</div>
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
void loop() {
  server.handleClient();
}

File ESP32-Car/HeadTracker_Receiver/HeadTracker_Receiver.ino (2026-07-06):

/**
 * ============================================================
 *  HEAD TRACKER RECEIVER — Car ESP32
 *  Hardware : ESP32 Dev Module
 *  Role     : Receives head angles (pitch, yaw) from the
 *             MPU-9250 head tracker unit via ESP-NOW,
 *             and drives Pan/Tilt servos.
 *             Motors are intentionally DISABLED in this sketch.
 * ============================================================
 */

#include <esp_now.h>
#include <WiFi.h>

// ----------------------------------------------------------
// SERVO PIN DEFINITIONS  (GPIO 21 = Pan, GPIO 22 = Tilt)
// ----------------------------------------------------------
#define SERVO_PAN   21
#define SERVO_TILT  22

// ----------------------------------------------------------
// Servo PWM (50 Hz, 16-bit for fine resolution)
// ----------------------------------------------------------
const int SERVO_FREQ = 50;
const int SERVO_RES  = 16;
const int SERVO_MIN  = 1638;   // 500 µs  -> 0°
const int SERVO_MAX  = 8192;   // 2500 µs -> 180°

// ----------------------------------------------------------
// Servo physical limits and neutral positions
// Pan center: 90° = straight ahead
// Tilt center: 110° = straight ahead (biased so servo has
//              more travel upward: 110->40 = 70° up range)
// ----------------------------------------------------------
const int PAN_CENTER   = 113;
const int TILT_CENTER  = 135;   // shifted so servo has travel both up and down
const int SERVO_MIN_ANG = 40;
const int SERVO_MAX_ANG = 180;

// Sensitivity: degrees of servo movement per degree of head movement
const float YAW_SCALE   = 1.5f;  // wider pan range
const float PITCH_SCALE = 1.8f;  // fuller tilt range

// ----------------------------------------------------------
// Smoothing: higher = more responsive, lower = smoother
// ----------------------------------------------------------
const float SMOOTH = 0.20f;

// ----------------------------------------------------------
// Timeout: if no data for this long, return to center
// ----------------------------------------------------------
const unsigned long TIMEOUT_MS = 800;

// ----------------------------------------------------------
// Data structure — must match HeadTracker exactly
// ----------------------------------------------------------
typedef struct HeadTrackerData {
    float pitch;
    float yaw;
    float roll;
} HeadTrackerData;

HeadTrackerData incoming = {0.0f, 0.0f, 0.0f};
unsigned long lastRecvMs = 0;
bool dataReceived = false;

// Current smoothed servo angles
float currentPan  = PAN_CENTER;
float currentTilt = TILT_CENTER;

// Yaw "zero" — the compass heading when the user is looking
// straight ahead. Set by pressing the BOOT button (GPIO 0).
float yawZero = 0.0f;
bool  yawZeroSet = false;

// ----------------------------------------------------------
// Servo helpers
// ----------------------------------------------------------
void writeServo(int pin, int angleDeg) {
  angleDeg = constrain(angleDeg, 0, 180);
  int duty = map(angleDeg, 0, 180, SERVO_MIN, SERVO_MAX);
  ledcWrite(pin, duty);
}

// ----------------------------------------------------------
// ESP-NOW receive callback
// ----------------------------------------------------------
void OnDataRecv(const uint8_t* mac, const uint8_t* data, int len) {
  if (len == sizeof(incoming)) {
    memcpy(&incoming, data, sizeof(incoming));
    lastRecvMs = millis();
    dataReceived = true;

    // Auto-set yaw zero on first packet received
    if (!yawZeroSet) {
      yawZero = incoming.yaw;
      yawZeroSet = true;
      Serial.printf("Yaw zero set to: %.1f deg\n", yawZero);
    }
  }
}

// ----------------------------------------------------------
// Setup
// ----------------------------------------------------------
void setup() {
  Serial.begin(115200);
  Serial.println("\n=== Head Tracker Receiver Starting ===");

  // Servo PWM setup
  ledcAttach(SERVO_PAN,  SERVO_FREQ, SERVO_RES);
  ledcAttach(SERVO_TILT, SERVO_FREQ, SERVO_RES);

  // Start at center
  writeServo(SERVO_PAN,  PAN_CENTER);
  writeServo(SERVO_TILT, TILT_CENTER);

  // BOOT button for yaw re-zero (built-in on most ESP32 boards)
  pinMode(0, INPUT_PULLUP);

  // WiFi as station (required for ESP-NOW)
  WiFi.mode(WIFI_STA);
  Serial.print("Car MAC Address: ");
  Serial.println(WiFi.macAddress());

  // Init ESP-NOW
  if (esp_now_init() != ESP_OK) {
    Serial.println("Error initializing ESP-NOW");
    return;
  }
  esp_now_register_recv_cb(esp_now_recv_cb_t(OnDataRecv));

  Serial.println("ESP-NOW Ready. Waiting for head tracker data...");
  Serial.println("Tip: Press BOOT (GPIO 0) to re-zero the pan direction.");
}

// ----------------------------------------------------------
// Loop
// ----------------------------------------------------------
void loop() {
  unsigned long now = millis();

  // Re-zero yaw on BOOT button press
  if (digitalRead(0) == LOW && yawZeroSet) {
    yawZero = incoming.yaw;
    Serial.printf("Yaw re-zeroed to: %.1f deg\n", yawZero);
    delay(300); // debounce
  }

  float targetPan  = PAN_CENTER;
  float targetTilt = TILT_CENTER;

  if (dataReceived && (now - lastRecvMs <= TIMEOUT_MS)) {
    // Pan: yaw delta from zero heading (gyro-integrated, turns right = positive)
    float yawDelta = incoming.yaw - yawZero;
    // Wrap to -180..+180
    if (yawDelta >  180.0f) yawDelta -= 360.0f;
    if (yawDelta < -180.0f) yawDelta += 360.0f;

    targetPan  = PAN_CENTER  - yawDelta * YAW_SCALE;  // negated: turn right = pan right

    // Tilt: pitch up (negative pitch from IMU) = servo toward SERVO_MIN_ANG (camera up)
    // pitch down (positive) = servo toward SERVO_MAX_ANG (camera down)
    // TILT_CENTER=110 biases the servo so it can travel 70° up and 40° down
    targetTilt = TILT_CENTER + incoming.pitch * PITCH_SCALE;
  }

  // Clamp to physical limits
  targetPan  = constrain(targetPan,  SERVO_MIN_ANG, SERVO_MAX_ANG);
  targetTilt = constrain(targetTilt, SERVO_MIN_ANG, SERVO_MAX_ANG);

  // Exponential smoothing
  currentPan  += (targetPan  - currentPan)  * SMOOTH;
  currentTilt += (targetTilt - currentTilt) * SMOOTH;

  writeServo(SERVO_PAN,  (int)currentPan);
  writeServo(SERVO_TILT, (int)currentTilt);

  // Debug print every second
  static unsigned long lastPrint = 0;
  if (now - lastPrint >= 1000) {
    lastPrint = now;
    if (dataReceived) {
      Serial.printf("Recv -> Pitch:%.1f Yaw:%.1f | Servo Pan:%d Tilt:%d\n",
        incoming.pitch, incoming.yaw, (int)currentPan, (int)currentTilt);
    } else {
      Serial.println("Waiting for head tracker...");
    }
  }

  delay(15);  // ~66Hz loop
}

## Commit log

2026-06-12 feat: initial Vision Hub firmware for AMB82-MINI
    - SoftAP on Ch1 (SSID: RobotCar-Demo) to avoid ESP-NOW interference
    - Dual ISP pipeline: H.264 VGA RTSP stream (Ch0) + RGB NPU feed (Ch3)
    - YOLOv4-Tiny object detection via on-chip NPU (COCO 80 classes)
    - Real-time OSD bounding boxes composited pre-H.264 encoding
    - Low-latency tuning: 1Mbps bitrate, GOP=10, conf=0.30, nms=0.45
    - VS Code tasks for one-click compile/upload via Arduino CLI
    Part of the AMB82-MINI autonomous robotic car platform (Open Day 2025)
    [RTSP.ino]
2026-06-26 feat(motor): migrate from L293D to dual TB6612FN motor driver
    - Replace single L293D H-bridge with two TB6612FNG ICs (one per side)
    - Left controller: FL motor on PWMA (pin 13), RL motor on PWMB (pin 19)
    - AIN1/AIN2: pins 4, 16 (RX2) | BIN1/BIN2: pins 17 (TX2), 18
    - Right controller: FR motor on PWMA (pin 26), RR motor on PWMB (pin 25)
    - AIN1/AIN2: pins 27, 14 | BIN1/BIN2: pins 32, 33
    - Use modern ESP32 ledcAttach() API (single-arg, Arduino-ESP32 3.x)
    - PWM: 5 kHz frequency, 8-bit resolution for quiet operation
    - FL and FR have inverted direction logic relative to RL/RR
    - Serial test menu: 1-4 for FL/FR/RL/RR, F/B for forward/backward
    [MotorTest.ino]
2026-06-26 feat: Add WebMotorControl sketch - ESP32 web dashboard for 4-motor control
    - Serves a responsive dark-theme HTML dashboard over WiFi (WebServer on port 80)
    - Four individual PWM sliders (-255 to +255) for FL, FR, RL, RR motors
    - Preserves exact pin assignments and direction logic from MotorTest.ino
    (FL/FR inverted logic, RL/RR standard logic, TB6612FNG dual H-bridge x2)
    - Uses modern ESP32 ledcAttach() API (Arduino core v3+)
    - Global STOP ALL and ALL FORWARD shortcut buttons
    - Real-time AJAX updates with debounce to avoid flooding the ESP32
    - Board: ESP32 Dev Module 30-pin, connects to Redmi Note 10 Pro hotspot
    [WebMotorControl.ino]
2026-06-26 feat(servo): v1.1 - Calibrated pan/tilt centres, limits and pan direction
    - Pan centre: slider 117 -> physical 113deg (camera straight-ahead)
    - Tilt centre: 135deg (camera straight-ahead)
    - Both servo axes hard-limited to 50-180deg (below 50 bracket collides)
    - Pan direction INVERTED: slider increase = camera moves RIGHT
    (physical = 230 - slider, where 230 = LIMIT_MIN+LIMIT_MAX)
    - Tilt direction unchanged: slider increase = camera moves UP
    - Boot positions: pan physical=113deg, tilt=135deg
    - HTML slider labels updated: LEFT/RIGHT for pan, DOWN/UP for tilt
    - SERVO_CENTER JS object ensures Centre buttons snap to correct values
    [WebMotorControl.ino]
2026-06-27 backup: working state before FR channel fix (FL/RL/RR confirmed working)
    [Base.3mf, Bottom Bracket.3mf, Bracket 2.3mf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]
2026-06-27 feat: complete hardware integration and FR channel fix
    - Fixed FR motor B-channel wiring mapping in WebMotorControl
    - Fully updated README.md to document the distributed 3-node architecture (Vision Hub, Car Node, Gesture Glove)
    - Documented feature set, hardware requirements, and setup steps for v1.1
    [WebMotorControl.ino]
2026-06-27 feat: migrate to ESP-NOW and Mecanum Kinematics
    - Removed HTTP Wi-Fi logic from Gesture_Glove
    - Implemented Mecanum kinematics (Pitch/Roll/Yaw) on ESP32-C3
    - Created new ESPNOW_Receiver firmware for the ESP32 Car Node
    - Integrated 500ms safety timeout for motor cutoff
    - Updated README.md to v1.2 architectural diagram
2026-06-27 feat(v1.3): Head Tracker Prototype
    - Created ESPNOW_ServoTracker.ino for absolute Pan/Tilt tracking
    - Expanded ESP-NOW CarCommand struct with raw pitch/roll/yaw_rate
    - Updated Glove and Receiver firmware to use the new struct
    - Updated README to document v1.3
2026-07-06 feat(v1.4): Head Tracker working with Gyro yaw integration and calibrated servo limits
